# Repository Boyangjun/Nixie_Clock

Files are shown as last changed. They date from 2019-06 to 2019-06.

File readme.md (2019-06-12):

First of all, what is a nixie clock?

They are essentially timekeeping clocks, but nixie clock uses **nixie tube** to show the time. Nixie tube is a kind of ion tube that uses the principle of gas nixie discharge to work, the color of nixie determines by the composition of gas filled in the tube, such as neon to red,  argon to light purple, mercury to light blue, helium to pink and so on.

Nixie tube has some characteristics, such as power supply of 170V (so you need to do special boost), it’s life span is about one or two years, and keeping the number to tubes for a long time may lead to the cathode of tube poisoning(harmless for humans), so if you want to display the time, you need to do some small actions to change the numbers.

Light nixie is comfortable to look at, it will be a cool clock if together with RGB, Wi-Fi, temperature and humidity sensors, it should be a cool clock.

## Component Selection

* **Nixie Tube** I chose the IN-14 from the former Soviet Union, a new one costs 100 yuan, and a second-hand costs 50 yuan. In addition to the 0-9 numbers, there are left and right decimal points to show. It has a nice color and high quality.
* **Main control chip**I chose Arduino atmega 328p , because it can be developed directly on Arduino IDE, which is convenient for Mac computers, and there are extension libraries that can simplify programming(although it’s not a good thing for learning)
* **Time Receive** I chose esp8266 12F to obtain global standard time via ump connection of NTP Server
* **Boost**I just buy others boost module which can boost 5V to 170V, I recommend to design by yourself but I don’t have time.
* **RGB**I chose ws2812, which is a common one, it show fast and accurate and can be develop easily by Arduino IDE.
* PS: I didn’t use **Time Chip** like DS1302, Its really a failure, if the connection to NTP Server is not good, time shows in a bad way like jumping a few seconds, and if no Wi-Fi, it is unable to obtain time. To solve this problem, I added  DS3231 time count module, so it only need to get time when switching on, even if the power cut off, the time can be continued by button battery power.

## Circuit Design

* Nixie Clock Driver: 74HC595 + A42triode, easy to design and saving IO ports.

## Program Design

Program consist of two parts: setup() and loop(), the former only run once after power on, while loop() runs once and once until power off. So setup() contains some initialize likeWi-Fi connection, NTP Server connection, RGB, etc. While Loop() keeps receiving time  every second (or faster) and some other functions.

Some great libraries here, Thanks to their author!

Wifi and NTP Server：https://github.com/bportaluri/WiFiEsp

75HC595 Driver：[GitHub - Simsso/ShiftRegister74HC595: Arduino library that simplifies the usage of shift registers](https://github.com/Simsso/ShiftRegister74HC595)

RGB Driver：https://github.com/adafruit/Adafruit_NeoPixel

## Finally
I really hope this will help you for designing nixie clock. Any questions or suggestions, e-mail me! (boyangjun@bupt.edu.cn)

[image:BA12CFBF-97E2-4782-B7CB-3B10783BA695-6988-0000322A6EA5FA8B/IMG_20190530_185942.jpg]

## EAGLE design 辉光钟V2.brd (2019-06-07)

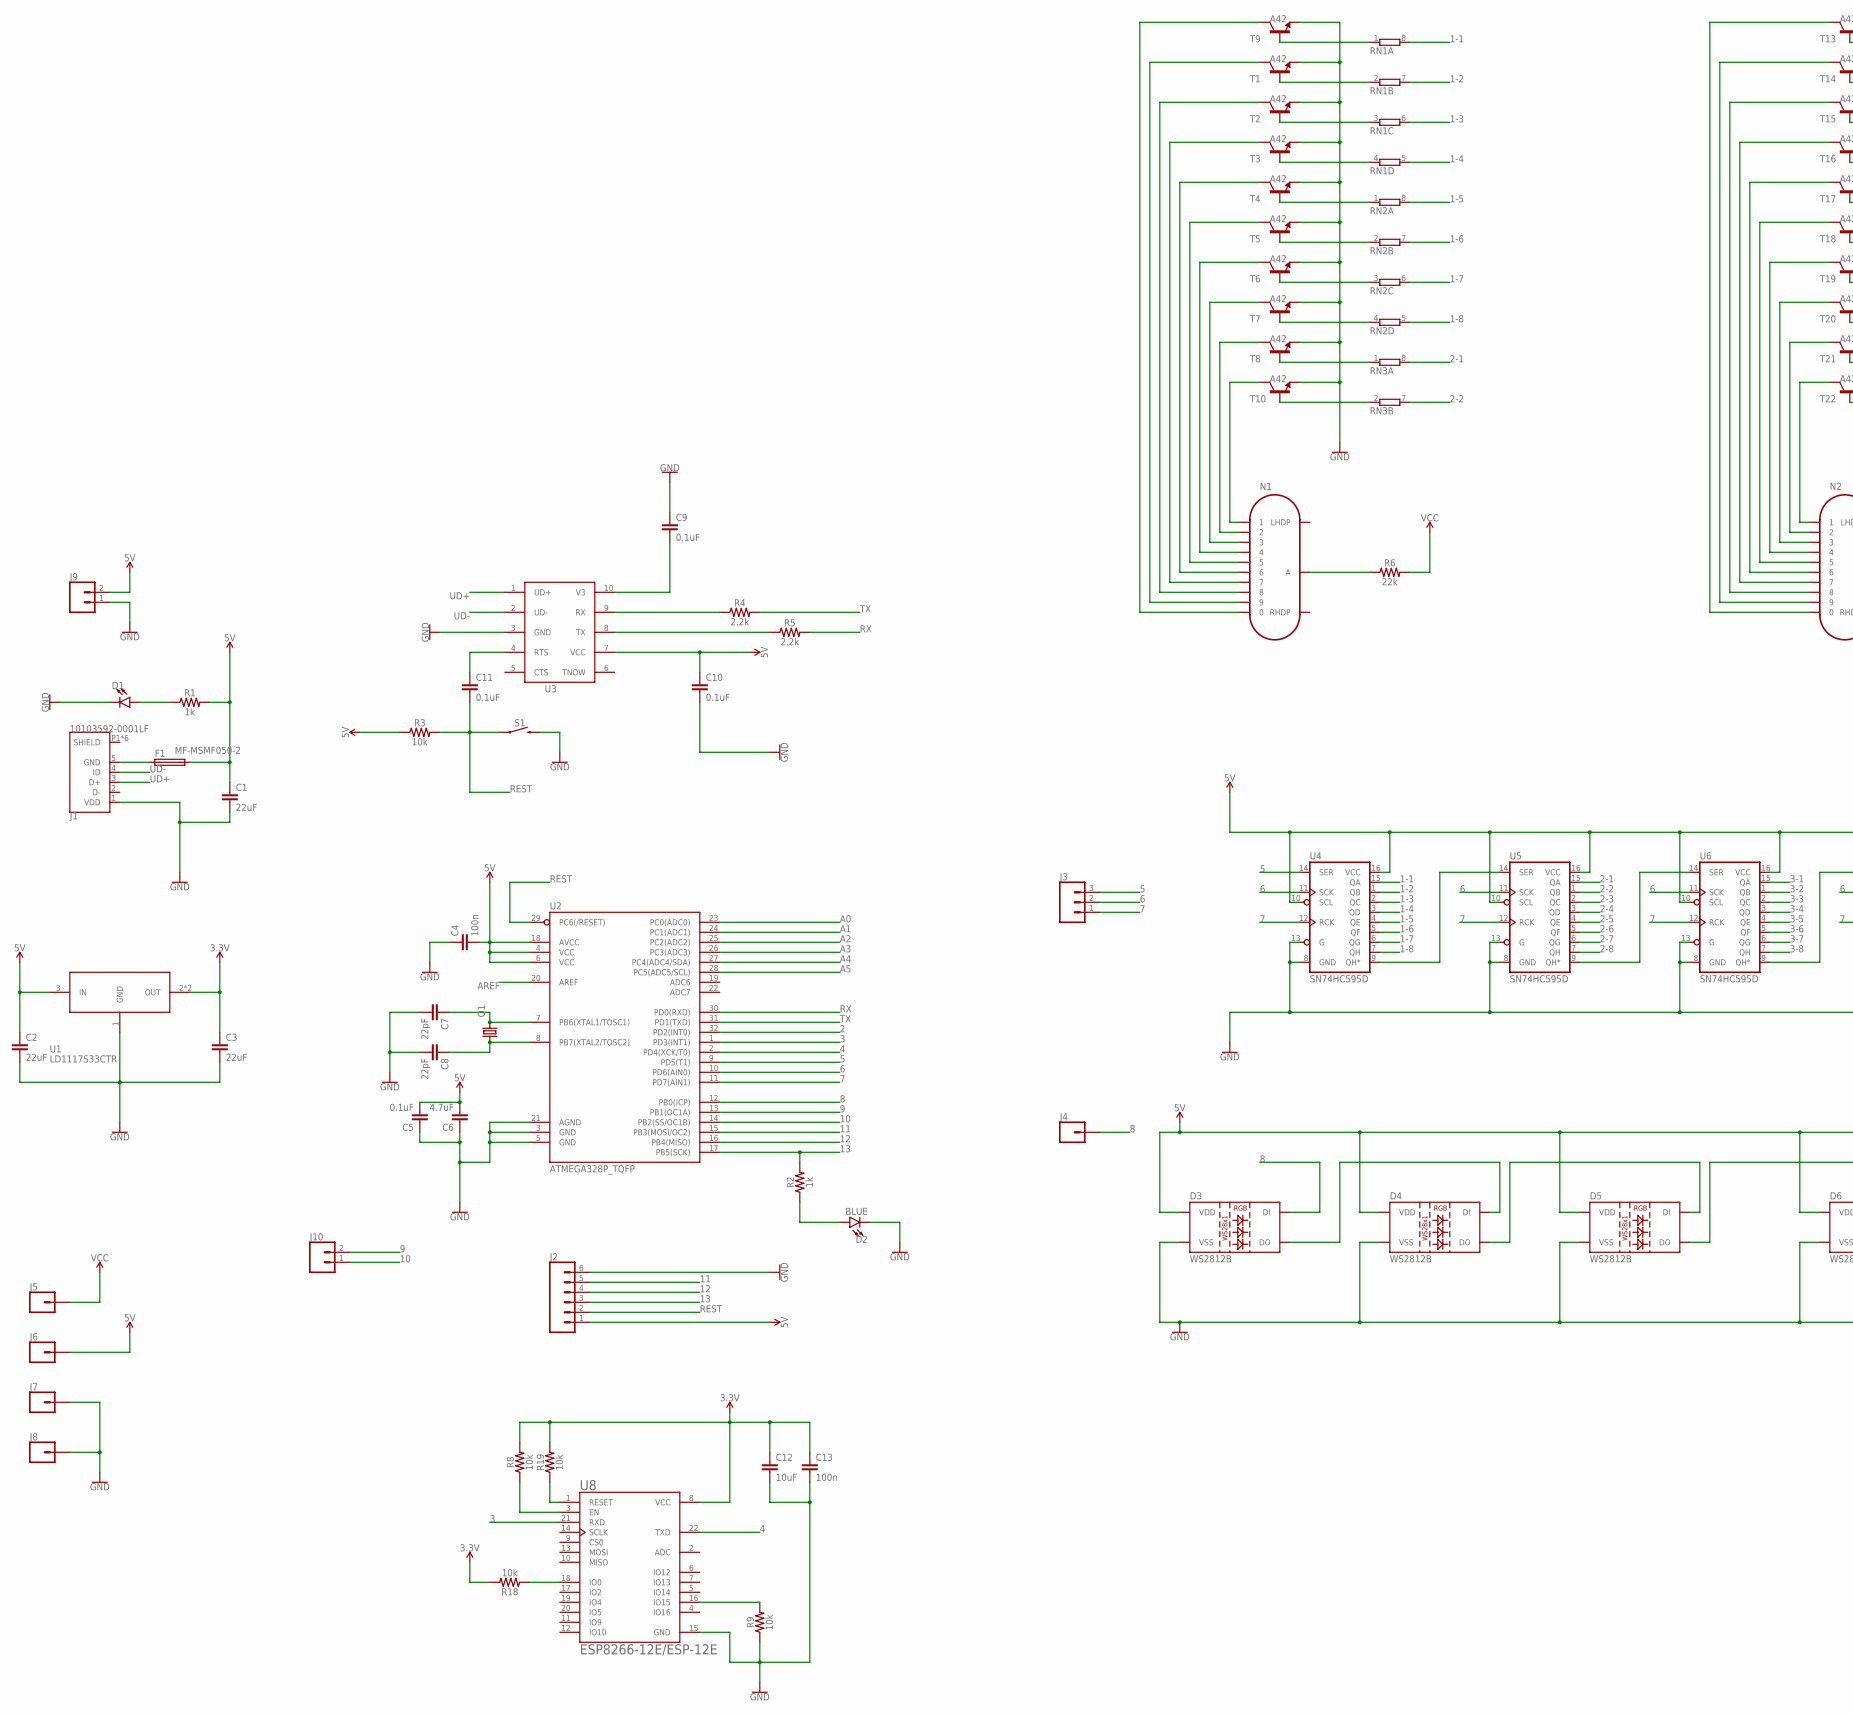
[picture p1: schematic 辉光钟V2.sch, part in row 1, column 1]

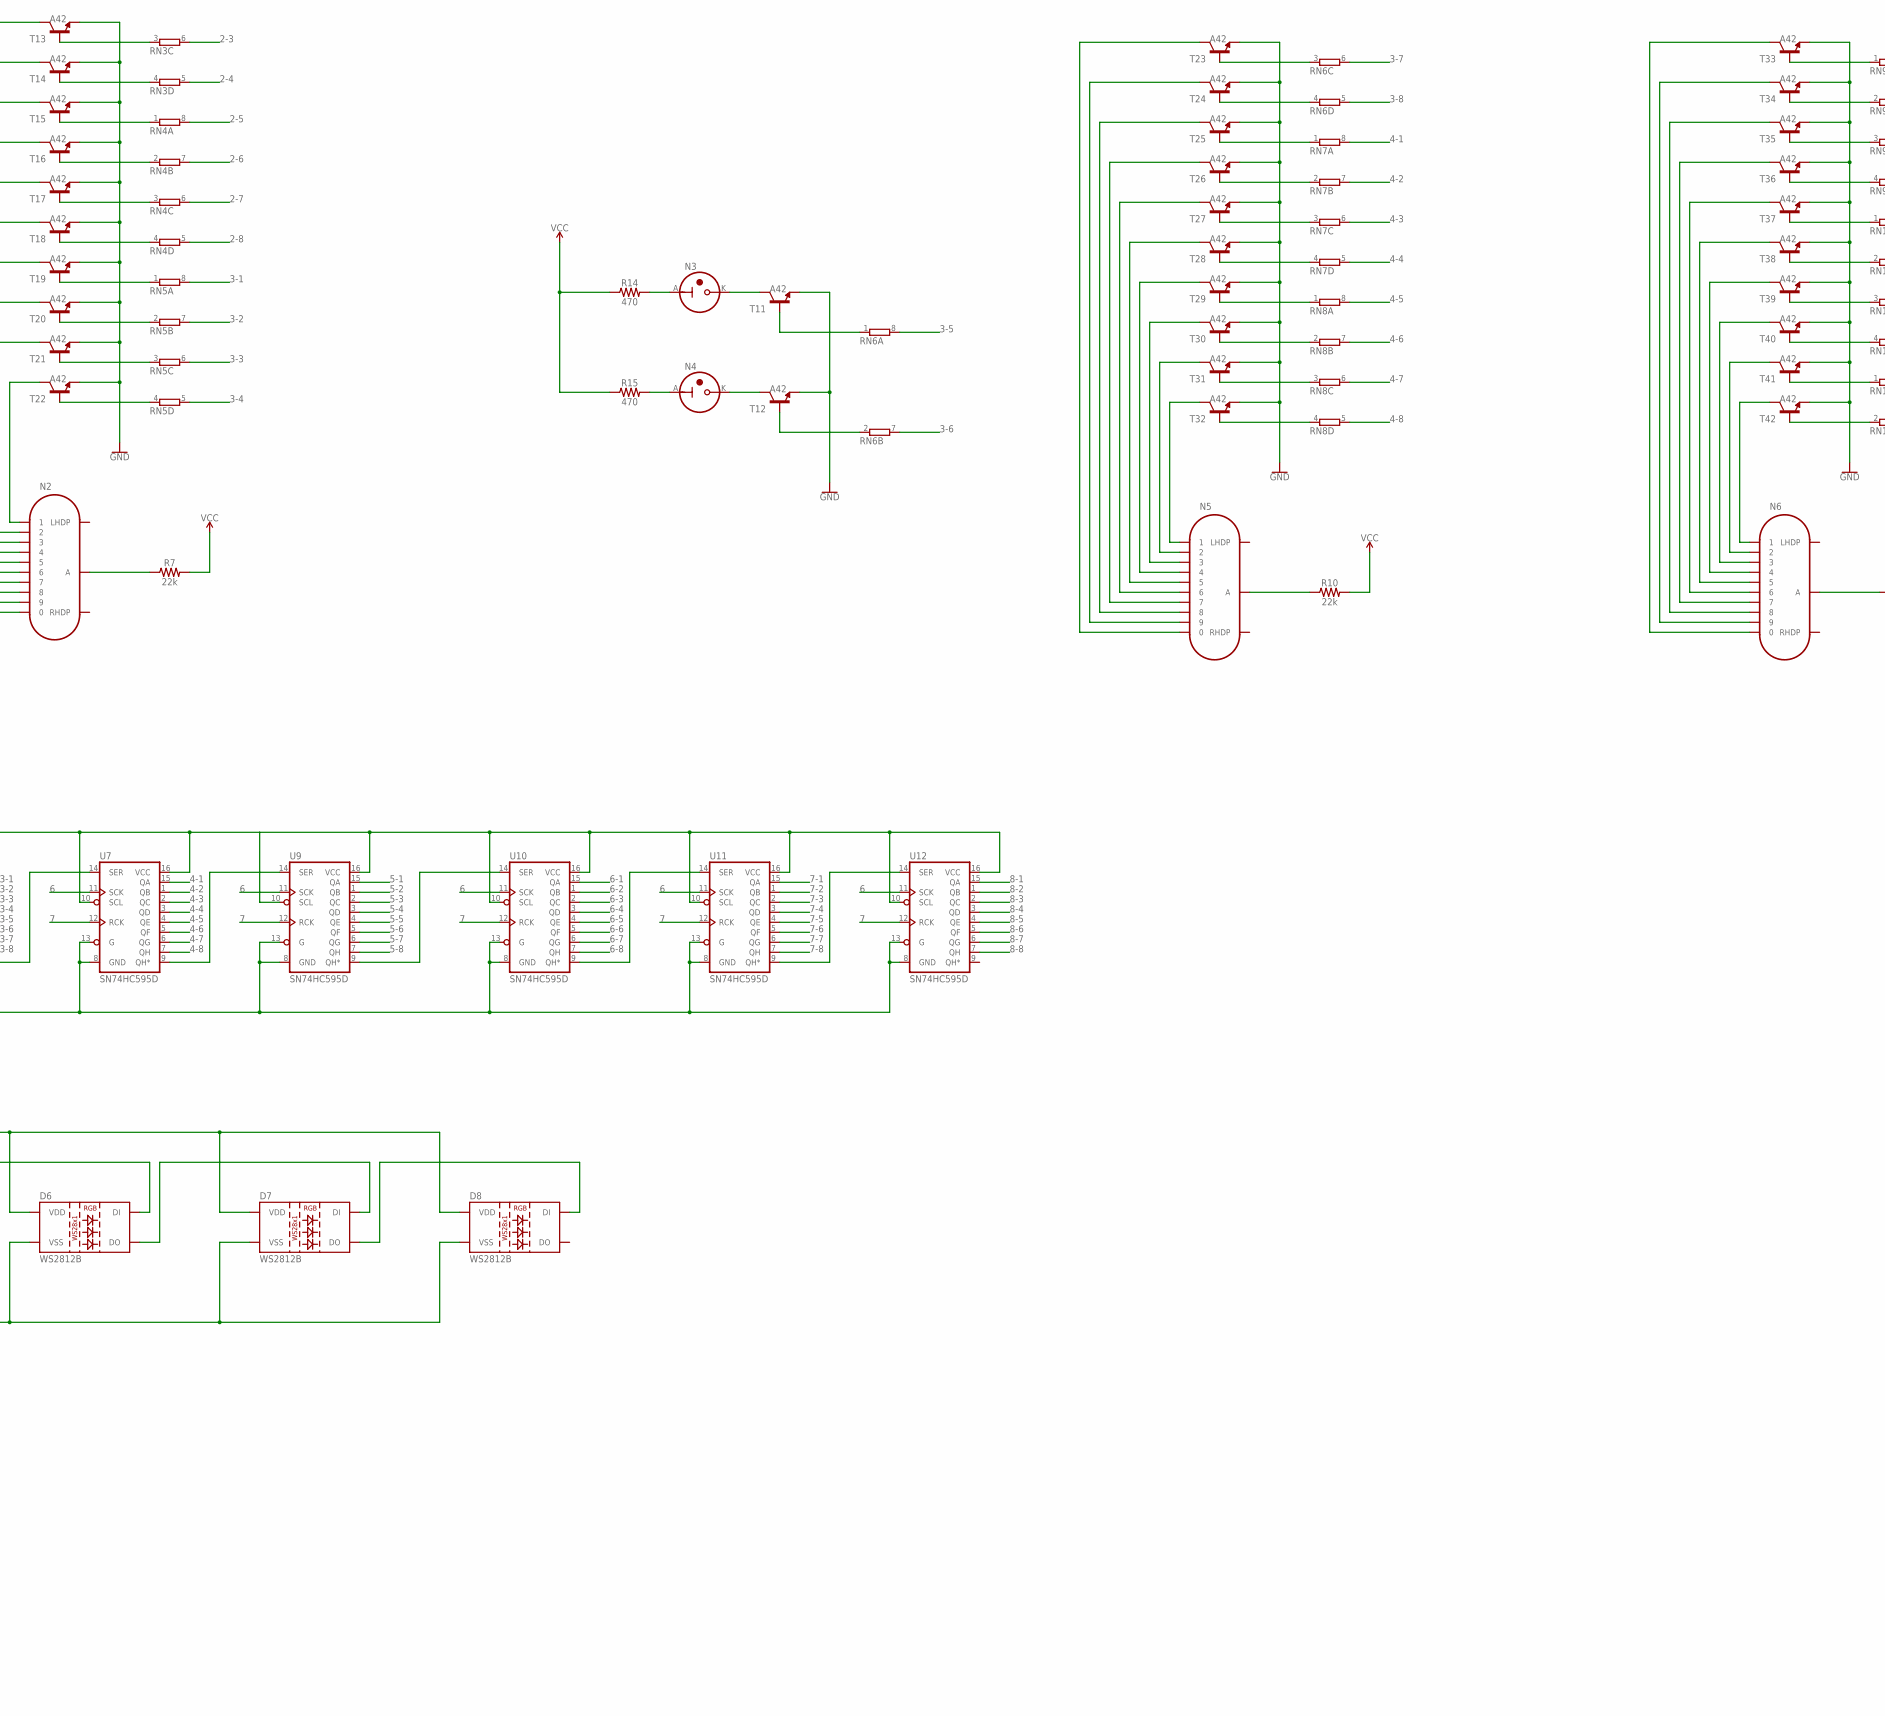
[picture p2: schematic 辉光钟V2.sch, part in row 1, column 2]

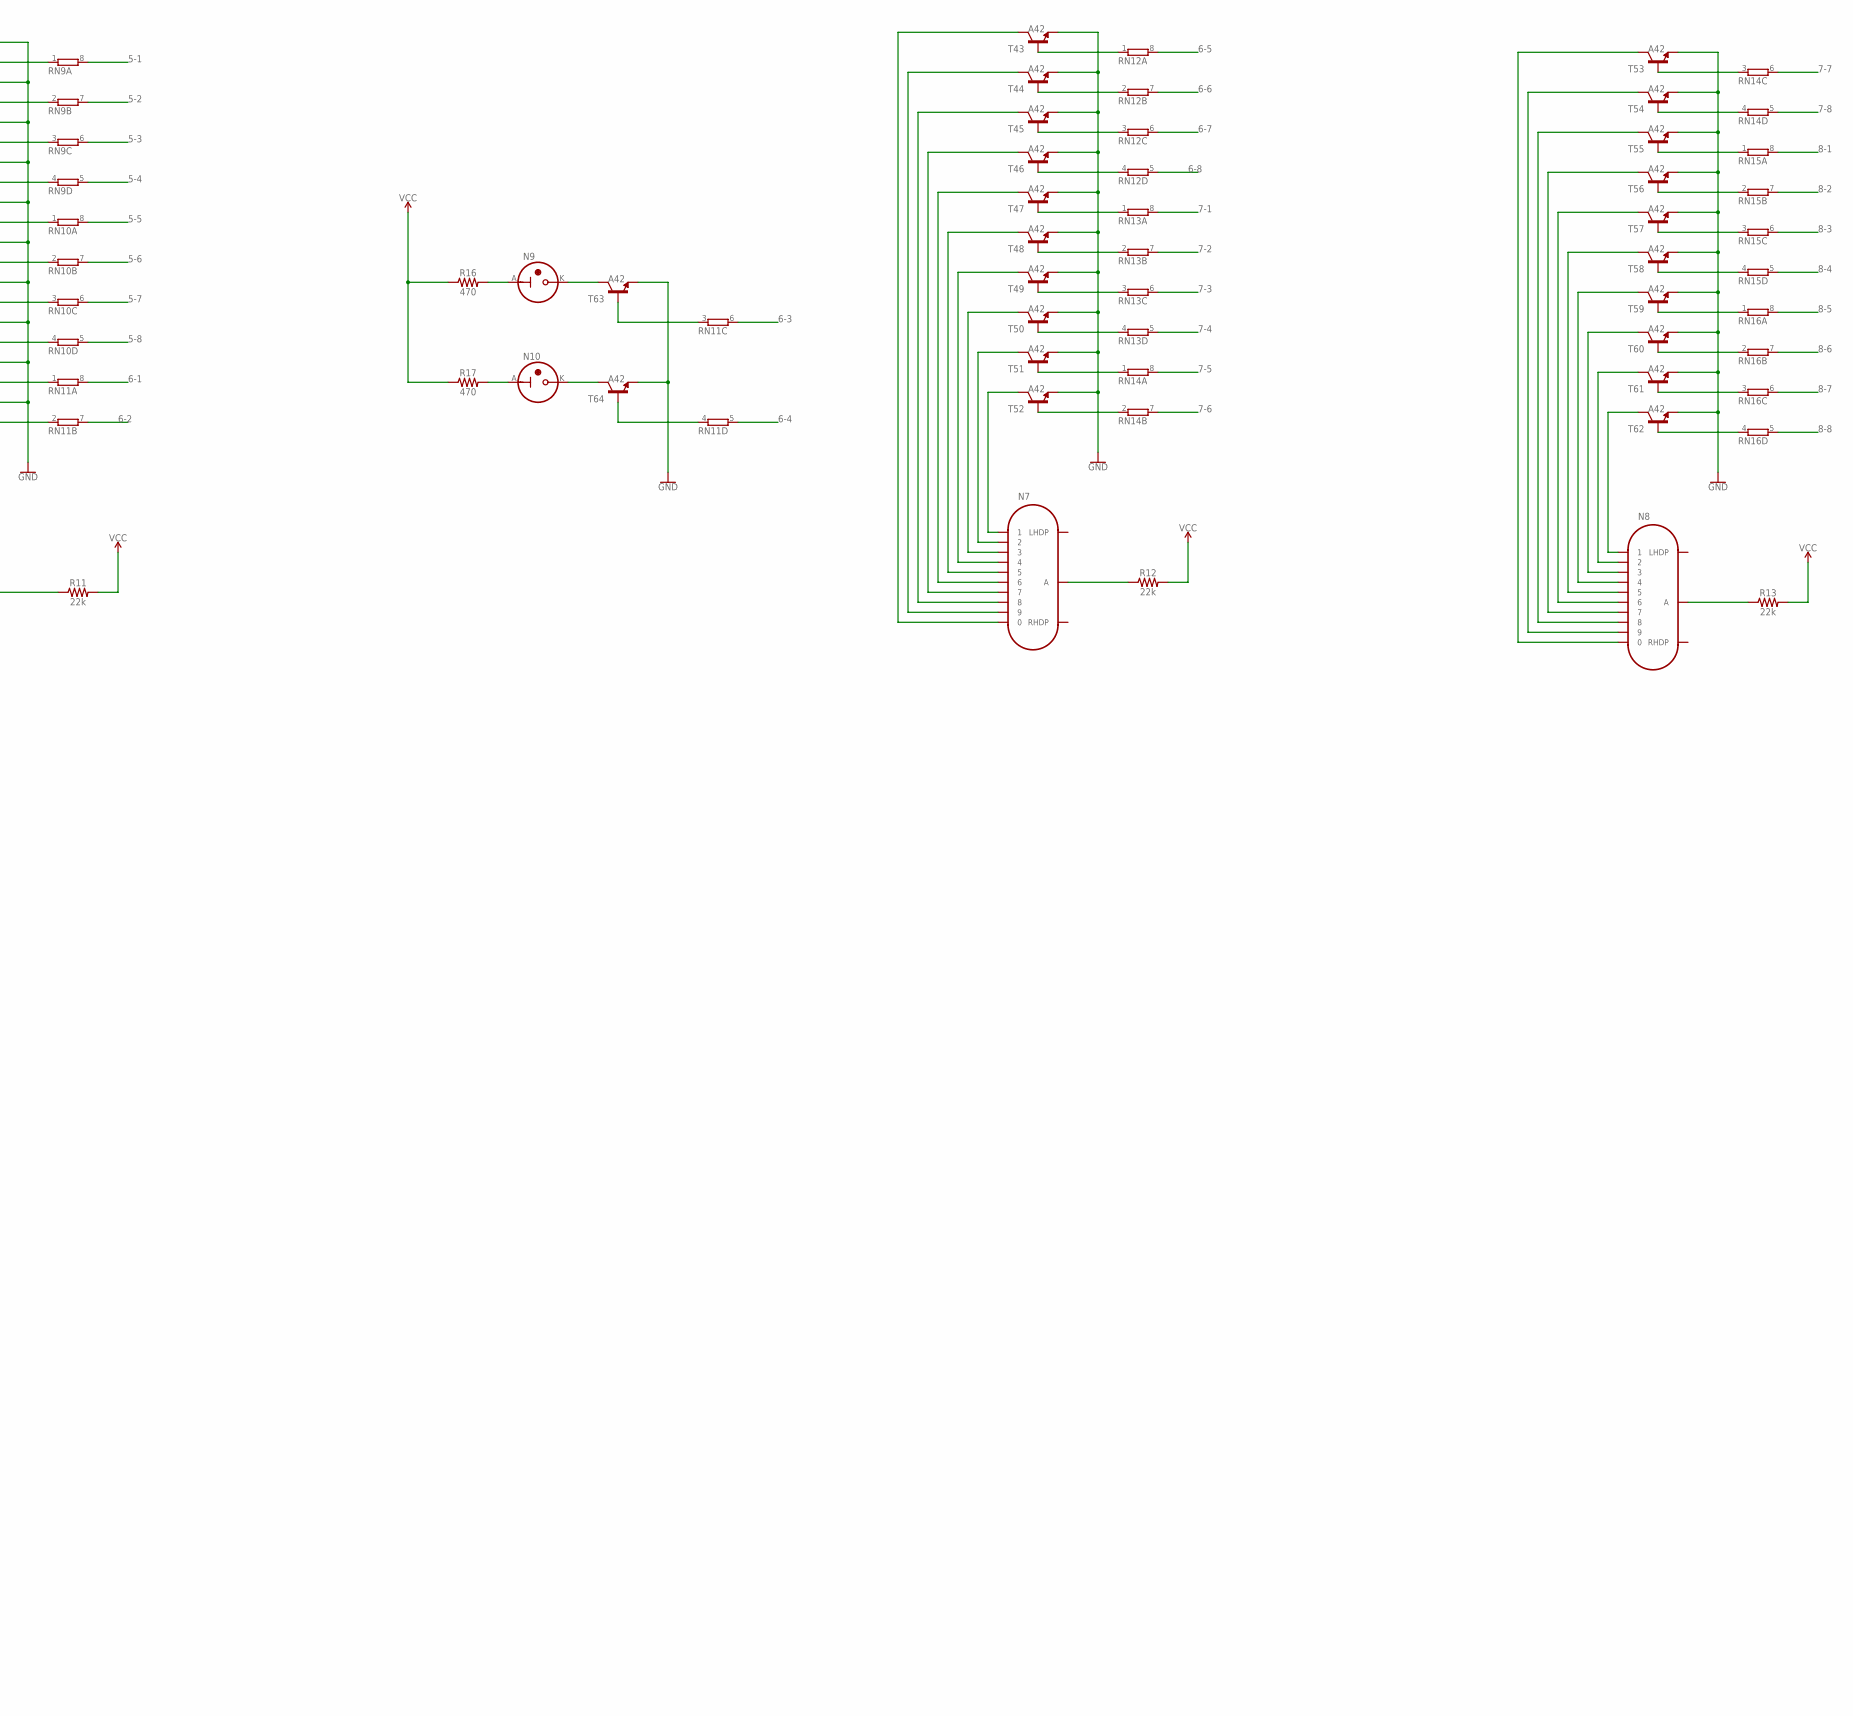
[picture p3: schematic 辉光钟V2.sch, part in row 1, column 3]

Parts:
C1, C2, C3: 22uF; 0805
C4, C13: 100n; 0603
C5, C9, C10, C11: 0.1uF; 0603
C6: 4.7uF; 0603
C7, C8: 22pF; 0603
C12: 10uF; 0603
D1: LED0603; LED-0603
D2: BLUE; LED-0603
D3, D4, D5, D6, D7, D8: WS2812B
F1: MF-MSMF050-2; FUSM1812X02
J1: 10103592-0001LF; AMPHENOL_10103592-0001LF
J2: CONN_06NO_SILK_FEMALE_PTH; 1X06_NO_SILK
J3: CONN_03; 1X03
J4, J5, J6, J7, J8: CONN_01; 1X01
J9, J10: CONN_02; 1X02
N1, N2, N5, N6, N7, N8: IN-14
N3, N4, N9, N10: IN-3
Q1: KX-7; 3.2X2.5_KX-7
R1, R2: 1k; 0603
R3, R8, R9, R18, R19: 10k; 0603
R4, R5: 2.2k; 0603
R6, R7, R10, R11, R12, R13: 22k; 0603
R14, R15, R16, R17: 470; 0603
RN1, RN2, RN3, RN4, RN5, RN6, RN7, RN8, RN9, RN10, RN11, RN12, RN13, RN14, RN15, RN16: 4R-N0603-ARC; 0603-ARC
S1: MOMENTARY-SWITCH-SPST-SMD-6.0X3.5MM; TACTILE_SWITCH_SMD_6.0X3.5MM
T1, T2, T3, T4, T5, T6, T7, T8, T9, T10, T11, T12, T13, T14, T15, T16, T17, T18, T19, T20, T21, T22, T23, T24, T25, T26, T27, T28, T29, T30, T31, T32, T33, T34, T35, T36, T37, T38, T39, T40, T41, T42, T43, T44, T45, T46, T47, T48, T49, T50, T51, T52, T53, T54, T55, T56, T57, T58, T59, T60, T61, T62, T63, T64: A42; SOT23
U1: LD1117S33CTR; SOT223
U2: ATMEGA328P_TQFP; TQFP32-08
U3: CH340ESMD; MSOP10
U4, U5, U6, U7, U9, U10, U11, U12: SN74HC595D; SO16
U8: ESP8266-12E/ESP-12E; XCVR_ESP8266-12E/ESP-12E

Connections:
1-1: RN1.8 (2), U4.15 (QA)
1-2: RN1.7 (2), U4.1 (QB)
1-3: RN1.6 (2), U4.2 (QC)
1-4: RN1.5 (2), U4.3 (QD)
1-5: RN2.8 (2), U4.4 (QE)
1-6: RN2.7 (2), U4.5 (QF)
1-7: RN2.6 (2), U4.6 (QG)
1-8: RN2.5 (2), U4.7 (QH)
2: U2.32 (PD2(INT0))
2-1: RN3.8 (2), U5.15 (QA)
2-2: RN3.7 (2), U5.1 (QB)
2-3: RN3.6 (2), U5.2 (QC)
2-4: RN3.5 (2), U5.3 (QD)
2-5: RN4.8 (2), U5.4 (QE)
2-6: RN4.7 (2), U5.5 (QF)
2-7: RN4.6 (2), U5.6 (QG)
2-8: RN4.5 (2), U5.7 (QH)
3: U2.1 (PD3(INT1)), U8.21 (RXD)
3-1: RN5.8 (2), U6.15 (QA)
3-2: RN5.7 (2), U6.1 (QB)
3-3: RN5.6 (2), U6.2 (QC)
3-4: RN5.5 (2), U6.3 (QD)
3-5: RN6.8 (2), U6.4 (QE)
3-6: RN6.7 (2), U6.5 (QF)
3-7: RN6.6 (2), U6.6 (QG)
3-8: RN6.5 (2), U6.7 (QH)
3.3V: C3.1, C12.1, C13.1, R8.2, R18.2, R19.2, U1.2 (OUT), U1.4 (OUT), U8.8 (VCC)
4: U2.2 (PD4(XCK/T0)), U8.22 (TXD)
4-1: RN7.8 (2), U7.15 (QA)
4-2: RN7.7 (2), U7.1 (QB)
4-3: RN7.6 (2), U7.2 (QC)
4-4: RN7.5 (2), U7.3 (QD)
4-5: RN8.8 (2), U7.4 (QE)
4-6: RN8.7 (2), U7.5 (QF)
4-7: RN8.6 (2), U7.6 (QG)
4-8: RN8.5 (2), U7.7 (QH)
5: J3.3, U2.9 (PD5(T1)), U4.14 (SER)
5-1: RN9.8 (2), U9.15 (QA)
5-2: RN9.7 (2), U9.1 (QB)
5-3: RN9.6 (2), U9.2 (QC)
5-4: RN9.5 (2), U9.3 (QD)
5-5: RN10.8 (2), U9.4 (QE)
5-6: RN10.7 (2), U9.5 (QF)
5-7: RN10.6 (2), U9.6 (QG)
5-8: RN10.5 (2), U9.7 (QH)
5V: C1.1, C2.1, C4.2, C5.2, C6.2, C10.1, D3.1 (VDD), D4.1 (VDD), D5.1 (VDD), D6.1 (VDD), D7.1 (VDD), D8.1 (VDD), F1.2, J2.1, J6.1, J9.2, R1.2, R3.1, U1.3 (IN), U2.4 (VCC), U2.6 (VCC), U2.18 (AVCC), U3.7 (VCC), U4.10 (SCL), U4.16 (VCC), U5.10 (SCL), U5.16 (VCC), U6.10 (SCL), U6.16 (VCC), U7.10 (SCL), U7.16 (VCC), U9.10 (SCL), U9.16 (VCC), U10.10 (SCL), U10.16 (VCC), U11.10 (SCL), U11.16 (VCC), U12.10 (SCL), U12.16 (VCC)
6: J3.2, U2.10 (PD6(AIN0)), U4.11 (SCK), U5.11 (SCK), U6.11 (SCK), U7.11 (SCK), U9.11 (SCK), U10.11 (SCK), U11.11 (SCK), U12.11 (SCK)
6-1: RN11.8 (2), U10.15 (QA)
6-2: RN11.7 (2), U10.1 (QB)
6-3: RN11.6 (2), U10.2 (QC)
6-4: RN11.5 (2), U10.3 (QD)
6-5: RN12.8 (2), U10.4 (QE)
6-6: RN12.7 (2), U10.5 (QF)
6-7: RN12.6 (2), U10.6 (QG)
6-8: RN12.5 (2), U10.7 (QH)
7: J3.1, U2.11 (PD7(AIN1)), U4.12 (RCK), U5.12 (RCK), U6.12 (RCK), U7.12 (RCK), U9.12 (RCK), U10.12 (RCK), U11.12 (RCK), U12.12 (RCK)
7-1: RN13.8 (2), U11.15 (QA)
7-2: RN13.7 (2), U11.1 (QB)
7-3: RN13.6 (2), U11.2 (QC)
7-4: RN13.5 (2), U11.3 (QD)
7-5: RN14.8 (2), U11.4 (QE)
7-6: RN14.7 (2), U11.5 (QF)
7-7: RN14.6 (2), U11.6 (QG)
7-8: RN14.5 (2), U11.7 (QH)
8: D3.4 (DI), J4.1, U2.12 (PB0(ICP))
8-1: RN15.8 (2), U12.15 (QA)
8-2: RN15.7 (2), U12.1 (QB)
8-3: RN15.6 (2), U12.2 (QC)
8-4: RN15.5 (2), U12.3 (QD)
8-5: RN16.8 (2), U12.4 (QE)
8-6: RN16.7 (2), U12.5 (QF)
8-7: RN16.6 (2), U12.6 (QG)
8-8: RN16.5 (2), U12.7 (QH)
9: J10.2, U2.13 (PB1(OC1A))
10: J10.1, U2.14 (PB2(SS/OC1B))
11: J2.5, U2.15 (PB3(MOSI/OC2))
12: J2.4, U2.16 (PB4(MISO))
13: J2.3, R2.2, U2.17 (PB5(SCK))
A0: U2.23 (PC0(ADC0))
A1: U2.24 (PC1(ADC1))
A2: U2.25 (PC2(ADC2))
A3: U2.26 (PC3(ADC3))
A4: U2.27 (PC4(ADC4/SDA))
A5: U2.28 (PC5(ADC5/SCL))
AREF: U2.20 (AREF)
GND: C1.2, C2.2, C3.2, C4.1, C5.1, C6.1, C7.2, C8.2, C9.1, C10.2, C12.2, C13.2, D1.C, D2.C, D3.3 (VSS), D4.3 (VSS), D5.3 (VSS), D6.3 (VSS), D7.3 (VSS), D8.3 (VSS), J1.1 (VDD), J2.6, J7.1, J8.1, J9.1, R9.1, S1.2, T1.2 (E), T2.2 (E), T3.2 (E), T4.2 (E), T5.2 (E), T6.2 (E), T7.2 (E), T8.2 (E), T9.2 (E), T10.2 (E), T11.2 (E), T12.2 (E), T13.2 (E), T14.2 (E), T15.2 (E), T16.2 (E), T17.2 (E), T18.2 (E), T19.2 (E), T20.2 (E), T21.2 (E), T22.2 (E), T23.2 (E), T24.2 (E), T25.2 (E), T26.2 (E), T27.2 (E), T28.2 (E), T29.2 (E), T30.2 (E), T31.2 (E), T32.2 (E), T33.2 (E), T34.2 (E), T35.2 (E), T36.2 (E), T37.2 (E), T38.2 (E), T39.2 (E), T40.2 (E), T41.2 (E), T42.2 (E), T43.2 (E), T44.2 (E), T45.2 (E), T46.2 (E), T47.2 (E), T48.2 (E), T49.2 (E), T50.2 (E), T51.2 (E), T52.2 (E), T53.2 (E), T54.2 (E), T55.2 (E), T56.2 (E), T57.2 (E), T58.2 (E), T59.2 (E), T60.2 (E), T61.2 (E), T62.2 (E), T63.2 (E), T64.2 (E), U1.1 (GND), U2.3 (GND), U2.5 (GND), U2.21 (AGND), U3.3 (GND), U4.8 (GND), U4.13 (G), U5.8 (GND), U5.13 (G), U6.8 (GND), U6.13 (G), U7.8 (GND), U7.13 (G), U8.15 (GND), U9.8 (GND), U9.13 (G), U10.8 (GND), U10.13 (G), U11.8 (GND), U11.13 (G), U12.8 (GND), U12.13 (G)
unnamed: F1.1, J1.5 (GND)
unnamed: U4.9 (QH*), U5.14 (SER)
unnamed: U5.9 (QH*), U6.14 (SER)
unnamed: C7.1, Q1.3 (2), U2.7 (PB6(XTAL1/TOSC1))
unnamed: D1.A, R1.1
unnamed: C8.1, Q1.1, U2.8 (PB7(XTAL2/TOSC2))
unnamed: U6.9 (QH*), U7.14 (SER)
unnamed: D2.A, R2.1
unnamed: C11.1, U3.4 (RTS)
unnamed: N1.1, T10.3 (C)
unnamed: N1.2, T8.3 (C)
unnamed: N1.3, T7.3 (C)
unnamed: N1.4, T6.3 (C)
unnamed: N1.5, T5.3 (C)
unnamed: N1.6, T4.3 (C)
unnamed: N1.7, T3.3 (C)
unnamed: N1.8, T2.3 (C)
unnamed: N1.9, T1.3 (C)
unnamed: N1.0, T9.3 (C)
unnamed: RN1.1, T9.1 (B)
unnamed: RN1.2 (1), T1.1 (B)
unnamed: RN1.3 (1), T2.1 (B)
unnamed: RN1.4 (1), T3.1 (B)
unnamed: R4.1, U3.9 (RX)
unnamed: R5.1, U3.8 (TX)
unnamed: RN2.1, T4.1 (B)
unnamed: RN2.2 (1), T5.1 (B)
unnamed: C9.2, U3.10 (V3)
unnamed: RN2.3 (1), T6.1 (B)
unnamed: RN2.4 (1), T7.1 (B)
unnamed: N1.A, R6.1
unnamed: RN3.1, T8.1 (B)
unnamed: RN3.2 (1), T10.1 (B)
unnamed: N2.1, T22.3 (C)
unnamed: N2.2, T21.3 (C)
unnamed: N2.3, T20.3 (C)
unnamed: N2.4, T19.3 (C)
unnamed: N2.5, T18.3 (C)
unnamed: N2.6, T17.3 (C)
unnamed: N2.7, T16.3 (C)
unnamed: N2.8, T15.3 (C)
unnamed: N2.9, T14.3 (C)
unnamed: N2.0, T13.3 (C)
unnamed: N2.A, R7.1
unnamed: RN3.3 (1), T13.1 (B)
unnamed: RN3.4 (1), T14.1 (B)
unnamed: RN4.1, T15.1 (B)
unnamed: RN4.2 (1), T16.1 (B)
unnamed: RN4.3 (1), T17.1 (B)
unnamed: RN4.4 (1), T18.1 (B)
unnamed: RN5.1, T19.1 (B)
unnamed: RN5.2 (1), T20.1 (B)
unnamed: RN5.3 (1), T21.1 (B)
unnamed: RN5.4 (1), T22.1 (B)
unnamed: R8.1, U8.3 (EN)
unnamed: R9.2, U8.16 (IO15)
unnamed: U7.9 (QH*), U9.14 (SER)
unnamed: N5.1, T32.3 (C)
unnamed: N5.2, T31.3 (C)
unnamed: N5.3, T30.3 (C)
unnamed: N5.4, T29.3 (C)
unnamed: N5.5, T28.3 (C)
unnamed: N5.6, T27.3 (C)
unnamed: N5.7, T26.3 (C)
unnamed: N5.8, T25.3 (C)
unnamed: N5.9, T24.3 (C)
unnamed: N5.0, T23.3 (C)
unnamed: N5.A, R10.1
unnamed: RN6.3 (1), T23.1 (B)
unnamed: RN6.4 (1), T24.1 (B)
unnamed: RN7.1, T25.1 (B)
unnamed: RN7.2 (1), T26.1 (B)
unnamed: RN7.3 (1), T27.1 (B)
unnamed: RN7.4 (1), T28.1 (B)
unnamed: RN8.1, T29.1 (B)
unnamed: RN8.2 (1), T30.1 (B)
unnamed: RN8.3 (1), T31.1 (B)
unnamed: RN8.4 (1), T32.1 (B)
unnamed: N6.1, T42.3 (C)
unnamed: N6.2, T41.3 (C)
unnamed: N6.3, T40.3 (C)
unnamed: N6.4, T39.3 (C)
unnamed: N6.5, T38.3 (C)
unnamed: N6.6, T37.3 (C)
unnamed: N6.7, T36.3 (C)
unnamed: N6.8, T35.3 (C)
unnamed: N6.9, T34.3 (C)
unnamed: N6.0, T33.3 (C)
unnamed: N6.A, R11.1
unnamed: RN9.1, T33.1 (B)
unnamed: RN9.2 (1), T34.1 (B)
unnamed: RN9.3 (1), T35.1 (B)
unnamed: RN9.4 (1), T36.1 (B)
unnamed: RN10.1, T37.1 (B)
unnamed: RN10.2 (1), T38.1 (B)
unnamed: RN10.3 (1), T39.1 (B)
unnamed: RN10.4 (1), T40.1 (B)
unnamed: RN11.1, T41.1 (B)
unnamed: RN11.2 (1), T42.1 (B)
unnamed: N7.1, T52.3 (C)
unnamed: N7.2, T51.3 (C)
unnamed: N7.3, T50.3 (C)
unnamed: N7.4, T49.3 (C)
unnamed: N7.5, T48.3 (C)
unnamed: N7.6, T47.3 (C)
unnamed: N7.7, T46.3 (C)
unnamed: N7.8, T45.3 (C)
unnamed: N7.9, T44.3 (C)
unnamed: N7.0, T43.3 (C)
unnamed: N7.A, R12.1
unnamed: RN12.1, T43.1 (B)
unnamed: RN12.2 (1), T44.1 (B)
unnamed: RN12.3 (1), T45.1 (B)
unnamed: RN12.4 (1), T46.1 (B)
unnamed: RN13.1, T47.1 (B)
unnamed: RN13.2 (1), T48.1 (B)
unnamed: RN13.3 (1), T49.1 (B)
unnamed: RN13.4 (1), T50.1 (B)
unnamed: RN14.1, T51.1 (B)
unnamed: RN14.2 (1), T52.1 (B)
unnamed: N8.1, T62.3 (C)
unnamed: N8.2, T61.3 (C)
unnamed: N8.3, T60.3 (C)
unnamed: N8.4, T59.3 (C)
unnamed: N8.5, T58.3 (C)
unnamed: N8.6, T57.3 (C)
unnamed: N8.7, T56.3 (C)
unnamed: N8.8, T55.3 (C)
unnamed: N8.9, T54.3 (C)
unnamed: N8.0, T53.3 (C)
unnamed: N8.A, R13.1
unnamed: RN14.3 (1), T53.1 (B)
unnamed: RN14.4 (1), T54.1 (B)
unnamed: RN15.1, T55.1 (B)
unnamed: RN15.2 (1), T56.1 (B)
unnamed: RN15.3 (1), T57.1 (B)
unnamed: RN15.4 (1), T58.1 (B)
unnamed: RN16.1, T59.1 (B)
unnamed: RN16.2 (1), T60.1 (B)
unnamed: RN16.3 (1), T61.1 (B)
unnamed: RN16.4 (1), T62.1 (B)
unnamed: N3.A, R14.2
unnamed: N3.K, T11.3 (C)
unnamed: N4.A, R15.2
unnamed: N4.K, T12.3 (C)
unnamed: RN6.1, T11.1 (B)
unnamed: RN6.2 (1), T12.1 (B)
unnamed: N9.A, R16.2
unnamed: N9.K, T63.3 (C)
unnamed: N10.A, R17.2
unnamed: N10.K, T64.3 (C)
unnamed: RN11.3 (1), T63.1 (B)
unnamed: RN11.4 (1), T64.1 (B)
unnamed: R19.1, U8.1 (RESET)
unnamed: D3.2 (DO), D4.4 (DI)
unnamed: R18.1, U8.18 (IO0)
unnamed: D4.2 (DO), D5.4 (DI)
unnamed: D5.2 (DO), D6.4 (DI)
unnamed: D6.2 (DO), D7.4 (DI)
unnamed: D7.2 (DO), D8.4 (DI)
unnamed: U10.9 (QH*), U11.14 (SER)
unnamed: U11.9 (QH*), U12.14 (SER)
unnamed: U9.9 (QH*), U10.14 (SER)
REST: C11.2, J2.2, R3.2, S1.1, U2.29 (PC6(/RESET))
RX: R5.2, U2.30 (PD0(RXD))
SHIELD: J1.P1 (SHIELD), J1.P2 (SHIELD), J1.P3 (SHIELD), J1.P4 (SHIELD), J1.P5 (SHIELD), J1.P6 (SHIELD)
TX: R4.2, U2.31 (PD1(TXD))
UD+: J1.3 (D+), U3.1 (UD+)
UD-: J1.4 (ID), U3.2 (UD-)
VCC: J5.1, R6.2, R7.2, R10.2, R11.2, R12.2, R13.2, R14.1, R15.1, R16.1, R17.1

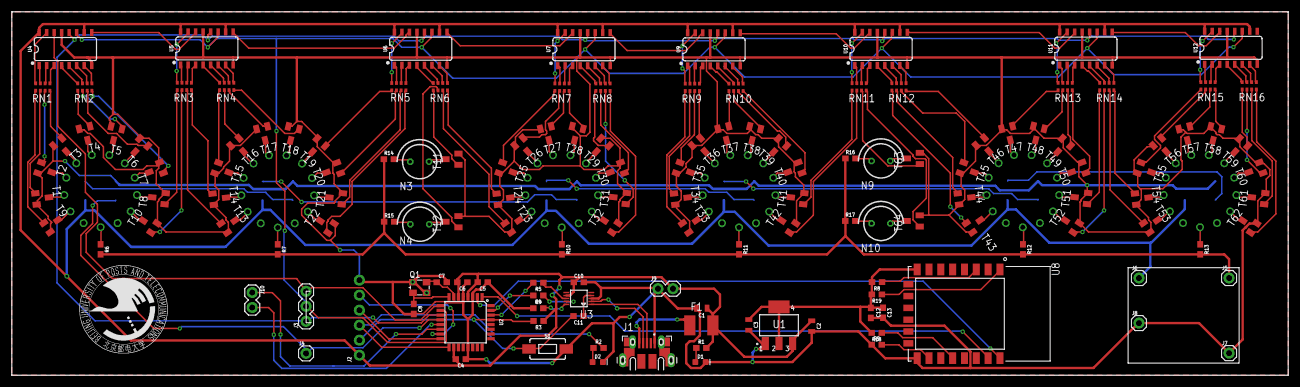
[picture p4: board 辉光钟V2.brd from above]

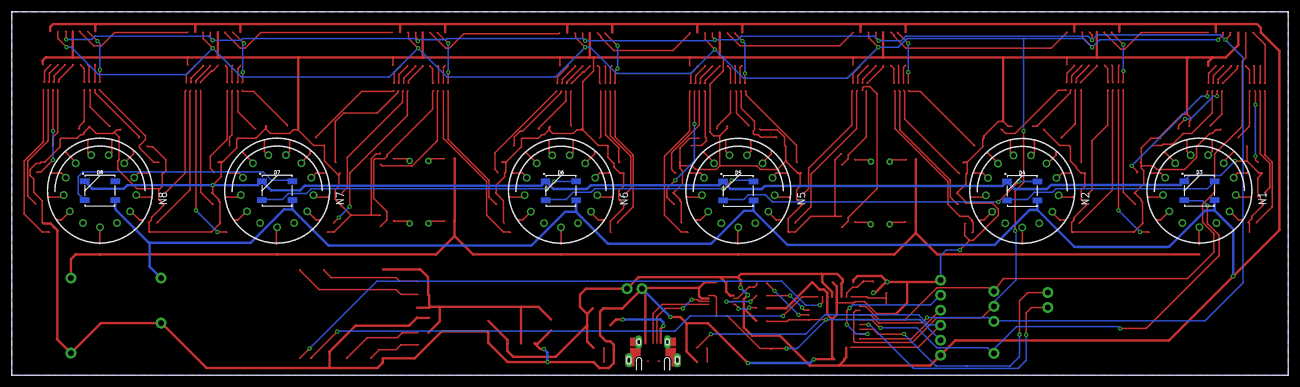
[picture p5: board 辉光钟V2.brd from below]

Board: 2 copper layers, 215.9 x 61.5 mm, 155 parts (12 on the bottom side), 248 nets.

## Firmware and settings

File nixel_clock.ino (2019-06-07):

//lby
#include <ShiftRegister74HC595.h>
#include "WiFiEsp.h"
#include "WiFiEspUdp.h"

#include<Adafruit_NeoPixel.h>
#define PIN 8

// create a global shift register object
// parameters: (number of shift registers, data pin, clock pin, latch pin)
ShiftRegister74HC595 sr (8, 5, 6, 7); 

Adafruit_NeoPixel strip = Adafruit_NeoPixel(6, PIN, NEO_RGB+NEO_KHZ800);
uint8_t brightness = 0;
uint8_t fadeAmount = 5;
uint8_t rb[7][3] = { {255, 0, 0}, {255, 125, 0}, {255, 255, 0}, {0, 255, 0}, {0, 155, 255}, {0, 0, 255}, {139, 0, 255}};


#ifndef HAVE_HWSERIAL1
#include "SoftwareSerial.h"
SoftwareSerial Serial1(4, 3); // RX, TX
#endif

char ssid[] = "lby";            // your network SSID (name)
char pass[] = "12345678";        // your network password
int status = WL_IDLE_STATUS;     // the Wifi radio's status

//IPAddress ip = "192.43.244.18";

char timeServer[] = "183.230.40.42";  // NTP server
//char timeServer[] = "0.cn.pool.ntp.org";  // NTP server
unsigned int localPort = 2390;        // local port to listen for UDP packets

const int NTP_PACKET_SIZE = 48;  // NTP timestamp is in the first 48 bytes of the message
const int UDP_TIMEOUT = 2000;    // timeout in miliseconds to wait for an UDP packet to arrive

byte packetBuffer[NTP_PACKET_SIZE]; // buffer to hold incoming and outgoing packets

WiFiEspUDP Udp;

uint8_t pinValues[8] = { B00000001, B00000100, B01110000, B00000000, B00000001, B00011100, B01000000, B00000000 };//初始化595寄存器，效果为显示6个1
 
void setup() {
  
  sr.setAll(pinValues);//显示6个1
  
  Serial.begin(9600);
  // initialize serial for ESP module
  Serial1.begin(9600);
  // initialize ESP module
  
  
  strip.begin();
  strip.setBrightness(100);//初始化RGB

  //初始化效果，紫灯闪烁
  for(int j = 0; j < 5; j++){
  for(int i = 0; i < 10; i++){
    for(int k = 0; k < 6; k++)
      strip.setPixelColor(k, 0, brightness, brightness);
    strip.show();
    brightness = brightness + fadeAmount;
    if(brightness <= 0 || brightness >= 50)
      fadeAmount = -fadeAmount;
    delay(40); 
    }
  }

  //Wi-Fi初始化，联网
  WiFi.init(&Serial1);
  
  // check for the presence of the shield
  if (WiFi.status() == WL_NO_SHIELD) {
    Serial.println("WiFi shield not present");
    // don't continue
    while (true);
  }

  // attempt to connect to WiFi network
  while ( status != WL_CONNECTED) {
  Serial.print("Attempting to connect to WPA SSID: ");
    Serial.println(ssid);
    // Connect to WPA/WPA2 network
    status = WiFi.begin(ssid, pass);
  }

  //联网完成后，显示彩虹灯
  for(int M = 0; M < 6; M++){
  for (uint8_t j = 0; j < 6; j++) {
  for (uint8_t k = 0; k < 6; k++)
    strip.setPixelColor(k, 0);
      for (int8_t i = 0; i <= j; i++){
        strip.setPixelColor(i, strip.Color(rb[(j-i) % 7][0], rb[(j-i) % 7][1], rb[(j-i) % 7][2]));
        strip.setBrightness(40);
      }
      strip.show();
  }
  }
  // you're connected now, so print out the data
  Serial.println("You're connected to the network");

  Udp.begin(localPort);
}

void loop() {
  
  sr.setAll(pinValues);
  
  //delay(10);

//----------------------------联网部分-----------------------------------------

  sendNTPpacket(timeServer); // send an NTP packet to a time server
  
  // wait for a reply for UDP_TIMEOUT miliseconds
  unsigned long startMs = millis();
  while (!Udp.available() && (millis() - startMs) < UDP_TIMEOUT) {}

  Serial.println(Udp.parsePacket());
  if (Udp.parsePacket()) {
    Serial.println("packet received");
    // We've received a packet, read the data from it into the buffer
    Udp.read(packetBuffer, NTP_PACKET_SIZE);

    // the timestamp starts at byte 40 of the received packet and is four bytes,
    // or two words, long. First, esxtract the two words:

    unsigned long highWord = word(packetBuffer[40], packetBuffer[41]);
    unsigned long lowWord = word(packetBuffer[42], packetBuffer[43]);
    // combine the four bytes (two words) into a long integer
    // this is NTP time (seconds since Jan 1 1900):
    unsigned long secsSince1900 = highWord << 16 | lowWord;
    Serial.print("Seconds since Jan 1 1900 = ");
    Serial.println(secsSince1900);

    // now convert NTP time into everyday time:
    Serial.print("Unix time = ");
    // Unix time starts on Jan 1 1970. In seconds, that's 2208988800:
    const unsigned long seventyYears = 2208988800UL;
    // subtract seventy years:
    unsigned long epoch = secsSince1900 - seventyYears;
    // print Unix time:
    Serial.println(epoch);


    // print the hour, minute and second:
    Serial.print("The UTC time is ");       // UTC is the time at Greenwich Meridian (GMT)
    //小时
    int hour = ((epoch  % 86400L) / 3600 + 8) % 24;
    int minute;
    int second;
    Serial.print(hour); // print the hour (86400 equals secs per day)
    Serial.print(':');
    if (((epoch % 3600) / 60) < 10) {
      // In the first 10 minutes of each hour, we'll want a leading '0'
      Serial.print('0');
      minute =0;
    }
    //分钟
    minute = (epoch  % 3600) / 60;
    Serial.print(minute); // print the minute (3600 equals secs per minute)
    Serial.print(':');
    if ((epoch % 60) < 10) {
      // In the first 10 seconds of each minute, we'll want a leading '0'
      Serial.print('0');
      second = 0;
    }
    //秒
    second = epoch % 60;
    Serial.println(second); // print the second
    UpdateDisplay(hour, minute, second, pinValues);
  }
  // wait ten seconds before asking for the time again
  delay(100);
  
  //delay(10);
}

//每次获取到时间后，设置各个寄存器状态
void UpdateDisplay(int hour, int minute, int second, uint8_t pinValues[8])
{
  int hour_shi = hour / 10 % 10;
  int hour_ge =  hour / 1  % 10;

  int minute_shi = minute / 10 % 10;
  int minute_ge =  minute / 1  % 10;

  int second_shi = second / 10 % 10;
  int second_ge =  second / 1  % 10;

//  if(minute_ge == 0){
//    for(int q = 1; q < 50; q++){
//      sr.setAllLow();
//      delay(20);
//    }
//    for(int q = 1; q < 50; q++){
//      for (int i = 0; i < 8; i++) {
//        sr.set(i, HIGH); // set single pin HIGH
//        delay(50); 
//      }
//    }
//  }

  switch(hour_shi){
    case 1:
      //doto
      pinValues[0] = pinValues[0] & B00000000;
      pinValues[1] = pinValues[1] & B11111100;
      pinValues[0] = pinValues[0] | B00000001;
      break;
    case 2:
      //doto
      pinValues[0] = pinValues[0] & B00000000;
      pinValues[1] = pinValues[1] & B11111100;
      pinValues[0] = pinValues[0] | B00000010;
      break;
    case 3:
      //doto
      pinValues[0] = pinValues[0] & B00000000;
      pinValues[1] = pinValues[1] & B11111100;
      pinValues[0] = pinValues[0] | B00000100;
      break;
    case 4:
      //doto
      pinValues[0] = pinValues[0] & B00000000;
      pinValues[1] = pinValues[1] & B11111100;
      pinValues[0] = pinValues[0] | B00001000;
      break;
    case 5:
      //doto
      pinValues[0] = pinValues[0] & B00000000;
      pinValues[1] = pinValues[1] & B11111100;
      pinValues[0] = pinValues[0] | B00010000;
      break;
    case 6:
      //doto
      pinValues[0] = pinValues[0] & B00000000;
      pinValues[1] = pinValues[1] & B11111100;
      pinValues[0] = pinValues[0] | B00100000;
      break;
    case 7:
      //doto
      pinValues[0] = pinValues[0] & B00000000;
      pinValues[1] = pinValues[1] & B11111100;
      pinValues[0] = pinValues[0] | B01000000;
      break;
    case 8:
      //doto
      pinValues[0] = pinValues[0] & B00000000;
      pinValues[1] = pinValues[1] & B11111100;
      pinValues[0] = pinValues[0] | B10000000;
      break;   
    case 9:
      //doto
      pinValues[1] = pinValues[1] & B11111100;
      pinValues[0] = pinValues[0] & B00000000;
      pinValues[1] = pinValues[1] | B00000001;
      break;
    case 0:
      //doto
      pinValues[1] = pinValues[1] & B11111100;
      pinValues[0] = pinValues[0] & B00000000;
      pinValues[1] = pinValues[1] | B00000010;
      break;           
  }
  //sr.setAll(pinValues);
  switch(hour_ge){
    case 1:
      //doto
      pinValues[1] = pinValues[1] & B00000011;
      pinValues[2] = pinValues[2] & B11110000;
      pinValues[1] = pinValues[1] | B00000100;
      break;
    case 2:
      //doto
      pinValues[1] = pinValues[1] & B00000011;
      pinValues[2] = pinValues[2] & B11110000;
      pinValues[1] = pinValues[1] | B00001000;
      break;
    case 3:
      //doto
      pinValues[1] = pinValues[1] & B00000011;
      pinValues[2] = pinValues[2] & B11110000;
      pinValues[1] = pinValues[1] | B00010000;
      break;
    case 4:
      //doto
      pinValues[1] = pinValues[1] & B00000011;
      pinValues[2] = pinValues[2] & B11110000;
      pinValues[1] = pinValues[1] | B00100000;
      break;
    case 5:
      //doto
      pinValues[1] = pinValues[1] & B00000011;
      pinValues[2] = pinValues[2] & B11110000;
      pinValues[1] = pinValues[1] | B01000000;
      break;
    case 6:
      //doto
      pinValues[1] = pinValues[1] & B00000011;
      pinValues[2] = pinValues[2] & B11110000;
      pinValues[1] = pinValues[1] | B10000000;
      break;
    case 7:
      //doto
      pinValues[1] = pinValues[1] & B00000011;
      pinValues[2] = pinValues[2] & B11110000;
      pinValues[2] = pinValues[2] | B00000001;
      break;
    case 8:
      //doto
      pinValues[1] = pinValues[1] & B00000011;
      pinValues[2] = pinValues[2] & B11110000;
      pinValues[2] = pinValues[2] | B00000010;
      break;   
    case 9:
      //doto
      pinValues[1] = pinValues[1] & B00000011;
      pinValues[2] = pinValues[2] & B11110000;
      pinValues[2] = pinValues[2] | B00000100;
      break;
    case 0:
      //doto
      pinValues[1] = pinValues[1] & B00000011;
      pinValues[2] = pinValues[2] & B11110000;
      pinValues[2] = pinValues[2] | B00001000;
      break;           
  }
  //sr.setAll(pinValues);
  switch(minute_shi){
    case 1:
      //doto
      pinValues[2] = pinValues[2] & B00111111;
      pinValues[3] = pinValues[3] & B00000000;
      pinValues[2] = pinValues[2] | B01000000;
      break;
    case 2:
      //doto
      pinValues[2] = pinValues[2] & B00111111;
      pinValues[3] = pinValues[3] & B00000000;
      pinValues[2] = pinValues[2] | B10000000;
      break;
    case 3:
      //doto
      pinValues[2] = pinValues[2] & B00111111;
      pinValues[3] = pinValues[3] & B00000000;
      pinValues[3] = pinValues[3] | B00000001;
      break;
    case 4:
      //doto
      pinValues[2] = pinValues[2] & B00111111;
      pinValues[3] = pinValues[3] & B00000000;
      pinValues[3] = pinValues[3] | B00000010;
      break;
    case 5:
      //doto
      pinValues[2] = pinValues[2] & B00111111;
      pinValues[3] = pinValues[3] & B00000000;
      pinValues[3] = pinValues[3] | B00000100;
      break;
    case 6:
      //doto
      pinValues[2] = pinValues[2] & B00111111;
      pinValues[3] = pinValues[3] & B00000000;
      pinValues[3] = pinValues[3] | B00001000;
      break;
    case 7:
      //doto
      pinValues[2] = pinValues[2] & B00111111;
      pinValues[3] = pinValues[3] & B00000000;
      pinValues[3] = pinValues[3] | B00010000;
      break;
    case 8:
      //doto
      pinValues[2] = pinValues[2] & B00111111;
      pinValues[3] = pinValues[3] & B00000000;
      pinValues[3] = pinValues[3] | B00100000;
      break;   
    case 9:
      //doto
      pinValues[2] = pinValues[2] & B00111111;
      pinValues[3] = pinValues[3] & B00000000;
      pinValues[3] = pinValues[3] | B01000000;
      break;
    case 0:
      //doto
      pinValues[2] = pinValues[2] & B00111111;
      pinValues[3] = pinValues[3] & B00000000;
      pinValues[3] = pinValues[3] | B10000000;
      break;           
  }
  //sr.setAll(pinValues);
  switch(minute_ge){
    case 1:
      //doto
      pinValues[4] = pinValues[4] & B00000000;
      pinValues[5] = pinValues[5] & B11111100;
      pinValues[4] = pinValues[4] | B00000001;
      break;
    case 2:
      //doto
      pinValues[4] = pinValues[4] & B00000000;
      pinValues[5] = pinValues[5] & B11111100;
      pinValues[4] = pinValues[4] | B00000010;
      break;
    case 3:
      //doto
      pinValues[4] = pinValues[4] & B00000000;
      pinValues[5] = pinValues[5] & B11111100;
      pinValues[4] = pinValues[4] | B00000100;
      break;
    case 4:
      //doto
      pinValues[4] = pinValues[4] & B00000000;
      pinValues[5] = pinValues[5] & B11111100;
      pinValues[4] = pinValues[4] | B00001000;
      break;
    case 5:
      //doto
      pinValues[4] = pinValues[4] & B00000000;
      pinValues[5] = pinValues[5] & B11111100;
      pinValues[4] = pinValues[4] | B00010000;
      break;
    case 6:
      //doto
      pinValues[4] = pinValues[4] & B00000000;
      pinValues[5] = pinValues[5] & B11111100;
      pinValues[4] = pinValues[4] | B00100000;
      break;
    case 7:
      //doto
      pinValues[4] = pinValues[4] & B00000000;
      pinValues[5] = pinValues[5] & B11111100;
      pinValues[4] = pinValues[4] | B01000000;
      break;
    case 8:
      //doto
      pinValues[4] = pinValues[4] & B00000000;
      pinValues[5] = pinValues[5] & B11111100;
      pinValues[4] = pinValues[4] | B10000000;
      break;   
    case 9:
      //doto
      pinValues[4] = pinValues[4] & B00000000;
      pinValues[5] = pinValues[5] & B11111100;
      pinValues[5] = pinValues[5] | B00000001;
      break;
    case 0:
      //doto
      pinValues[4] = pinValues[4] & B00000000;
      pinValues[5] = pinValues[5] & B11111100;
      pinValues[5] = pinValues[5] | B00000010;
      break;           
  }
  //sr.setAll(pinValues);
  switch(second_shi){
    case 1:
      //doto
      pinValues[5] = pinValues[5] & B00001111;
      pinValues[6] = pinValues[6] & B11000000;
      pinValues[5] = pinValues[5] | B00010000;
      break;
    case 2:
      //doto
      pinValues[5] = pinValues[5] & B00001111;
      pinValues[6] = pinValues[6] & B11000000;
      pinValues[5] = pinValues[5] | B00100000;
      break;
    case 3:
      //doto
      pinValues[5] = pinValues[5] & B00001111;
      pinValues[6] = pinValues[6] & B11000000;
      pinValues[5] = pinValues[5] | B01000000;
      break;
    case 4:
      //doto
      pinValues[5] = pinValues[5] & B00001111;
      pinValues[6] = pinValues[6] & B11000000;
      pinValues[5] = pinValues[5] | B10000000;
      break;
    case 5:
      //doto
      pinValues[5] = pinValues[5] & B00001111;
      pinValues[6] = pinValues[6] & B11000000;
      pinValues[6] = pinValues[6] | B00000001;
      break;
    case 6:
      //doto
      pinValues[5] = pinValues[5] & B00001111;
      pinValues[6] = pinValues[6] & B11000000;
      pinValues[6] = pinValues[6] | B00000010;
      break;
    case 7:
      //doto
      pinValues[5] = pinValues[5] & B00001111;
      pinValues[6] = pinValues[6] & B11000000;
      pinValues[6] = pinValues[6] | B00000100;
      break;
    case 8:
      //doto
      pinValues[5] = pinValues[5] & B00001111;
      pinValues[6] = pinValues[6] & B11000000;
      pinValues[6] = pinValues[6] | B00001000;
      break;   
    case 9:
      //doto
      pinValues[5] = pinValues[5] & B00001111;
      pinValues[6] = pinValues[6] & B11000000;
      pinValues[6] = pinValues[6] | B00010000;
      break;
    case 0:
      //doto
      pinValues[5] = pinValues[5] & B00001111;
      pinValues[6] = pinValues[6] & B11000000;
      pinValues[6] = pinValues[6] | B00100000;
      break;           
  }
  //sr.setAll(pinValues);
  switch(minute_ge){
    case 1:
      //doto
      pinValues[4] = pinValues[4] & B00000000;
      pinValues[5] = pinValues[5] & B11111100;
      pinValues[4] = pinValues[4] | B00000001;
      break;
    case 2:
      //doto
      pinValues[4] = pinValues[4] & B00000000;
      pinValues[5] = pinValues[5] & B11111100;
      pinValues[4] = pinValues[4] | B00000010;
      break;
    case 3:
      //doto
      pinValues[4] = pinValues[4] & B00000000;
      pinValues[5] = pinValues[5] & B11111100;
      pinValues[4] = pinValues[4] | B00000100;
      break;
    case 4:
      //doto
      pinValues[4] = pinValues[4] & B00000000;
      pinValues[5] = pinValues[5] & B11111100;
      pinValues[4] = pinValues[4] | B00001000;
      break;
    case 5:
      //doto
      pinValues[4] = pinValues[4] & B00000000;
      pinValues[5] = pinValues[5] & B11111100;
      pinValues[4] = pinValues[4] | B00010000;
      break;
    case 6:
      //doto
      pinValues[4] = pinValues[4] & B00000000;
      pinValues[5] = pinValues[5] & B11111100;
      pinValues[4] = pinValues[4] | B00100000;
      break;
    case 7:
      //doto
      pinValues[4] = pinValues[4] & B00000000;
      pinValues[5] = pinValues[5] & B11111100;
      pinValues[4] = pinValues[4] | B01000000;
      break;
    case 8:
      //doto
      pinValues[4] = pinValues[4] & B00000000;
      pinValues[5] = pinValues[5] & B11111100;
      pinValues[4] = pinValues[4] | B10000000;
      break;   
    case 9:
      //doto
      pinValues[4] = pinValues[4] & B00000000;
      pinValues[5] = pinValues[5] & B11111100;
      pinValues[5] = pinValues[5] | B00000001;
      break;
    case 0:
      //doto
      pinValues[4] = pinValues[4] & B00000000;
      pinValues[5] = pinValues[5] & B11111100;
      pinValues[5] = pinValues[5] | B00000010;
      break;           
  }
  //sr.setAll(pinValues);
  switch(second_ge){
    case 1:
      //doto
      pinValues[6] = pinValues[6] & B00111111;
      pinValues[7] = pinValues[7] & B00000000;
      pinValues[6] = pinValues[6] | B01000000;
      break;
    case 2:
      //doto
      pinValues[6] = pinValues[6] & B00111111;
      pinValues[7] = pinValues[7] & B00000000;
      pinValues[6] = pinValues[6] | B10000000;
      break;
    case 3:
      //doto
      pinValues[6] = pinValues[6] & B00111111;
      pinValues[7] = pinValues[7] & B00000000;
      pinValues[7] = pinValues[7] | B00000001;
      break;
    case 4:
      //doto
      pinValues[6] = pinValues[6] & B00111111;
      pinValues[7] = pinValues[7] & B00000000;
      pinValues[7] = pinValues[7] | B00000010;
      break;
    case 5:
      //doto
      pinValues[6] = pinValues[6] & B00111111;
      pinValues[7] = pinValues[7] & B00000000;
      pinValues[7] = pinValues[7] | B00000100;
      break;
    case 6:
      //doto
      pinValues[6] = pinValues[6] & B00111111;
      pinValues[7] = pinValues[7] & B00000000;
      pinValues[7] = pinValues[7] | B00001000;
      break;
    case 7:
      //doto
      pinValues[6] = pinValues[6] & B00111111;
      pinValues[7] = pinValues[7] & B00000000;
      pinValues[7] = pinValues[7] | B00010000;
      break;
    case 8:
      //doto
      pinValues[6] = pinValues[6] & B00111111;
      pinValues[7] = pinValues[7] & B00000000;
      pinValues[7] = pinValues[7] | B00100000;
      break;   
    case 9:
      //doto
      pinValues[6] = pinValues[6] & B00111111;
      pinValues[7] = pinValues[7] & B00000000;
      pinValues[7] = pinValues[7] | B01000000;
      break;
    case 0:
      //doto
      pinValues[6] = pinValues[6] & B00111111;
      pinValues[7] = pinValues[7] & B00000000;
      pinValues[7] = pinValues[7] | B10000000;
      break;           
  }
  sr.setAll(pinValues);
}

void sendNTPpacket(char *ntpSrv)
{
  // set all bytes in the buffer to 0
  memset(packetBuffer, 0, NTP_PACKET_SIZE);
  // Initialize values needed to form NTP request
  // (see URL above for details on the packets)

  packetBuffer[0] = 0b11100011;   // LI, Version, Mode
  packetBuffer[1] = 0;     // Stratum, or type of clock
  packetBuffer[2] = 6;     // Polling Interval
  packetBuffer[3] = 0xEC;  // Peer Clock Precision
  // 8 bytes of zero for Root Delay & Root Dispersion
  packetBuffer[12]  = 49;
  packetBuffer[13]  = 0x4E;
  packetBuffer[14]  = 49;
  packetBuffer[15]  = 52;

  // all NTP fields have been given values, now
  // you can send a packet requesting a timestamp:
  Udp.beginPacket(ntpSrv, 123); //NTP requests are to port 123

  Udp.write(packetBuffer, NTP_PACKET_SIZE);

  Udp.endPacket();
}

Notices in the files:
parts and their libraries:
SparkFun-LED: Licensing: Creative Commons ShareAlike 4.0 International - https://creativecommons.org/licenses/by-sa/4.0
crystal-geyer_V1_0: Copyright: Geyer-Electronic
